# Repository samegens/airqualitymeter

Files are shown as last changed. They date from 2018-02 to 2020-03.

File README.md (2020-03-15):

# Air quality meter
Air quality meter using of-the-shelf components to measure dust particles, CO2, benzene and other nasty stuff.

# Prerequisites
- [Visual Studio Community](https://www.visualstudio.com/vs/community/)
- [Visual Micro](http://www.visualmicro.com)
- [Arduino core for ESP8266](https://github.com/esp8266/Arduino)

# Hardware
- [Wemos D1 Mini Lite](https://www.tinytronics.nl/shop/nl/arduino/wemos/wemos-d1-mini-lite-esp8285-ch340)
- [SDS-011 dust sensor](https://www.tinytronics.nl/shop/nl/sensoren/temperatuur-lucht-vochtigheid/nova-sds011-hoge-precisie-laser-stofsensor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)
- [3x TM1637 4-digit display](https://www.tinytronics.nl/shop/nl/verlichting/led-segment-display/robotdyn-segmenten-display-module-4-karakters-decimalen-wit-tm1637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)
- [MQ-135 gas sensor](https://www.tinytronics.nl/shop/nl/sensoren/temperatuur-lucht-vochtigheid/mq-135-gas-sensor-module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)
- breadboard
- wires, [male to male](https://www.tinytronics.nl/shop/nl/kabels/prototype-draden/dupont-jumper-draad-male-male-10cm-10-draden) and [male to female](https://www.tinytronics.nl/shop/nl/kabels/prototype-draden/dupont-jumper-draad-male-female-10cm-10-draden)
- enclosure, I used a cardboard box of 8cm x 21cm x 15cm
- power bank, with a USB cable that ends in a micro-USB connector
- stuff to attach the MQ-135 and displays to the enclosure. I used some electric wire (see photos).

# Schematic

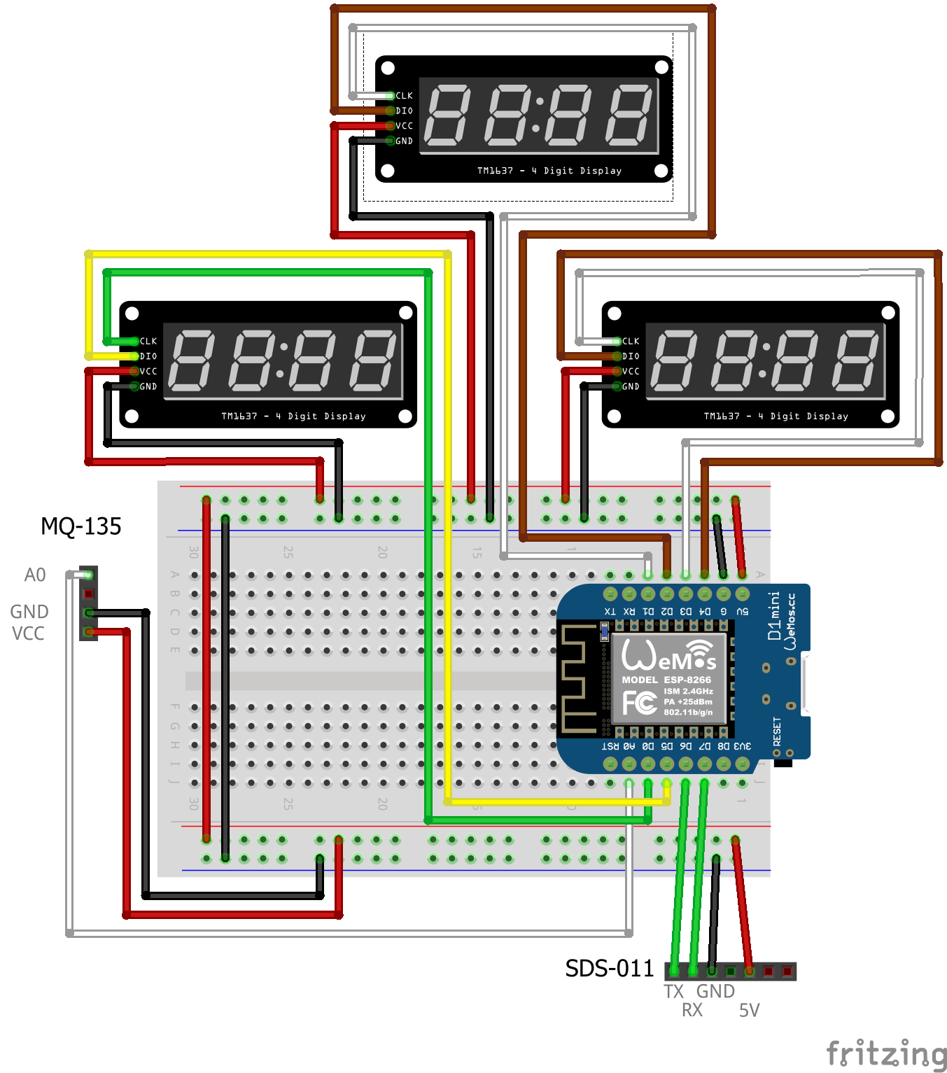
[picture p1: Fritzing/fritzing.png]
Fritzing


# Software

1. Open AirQualityMeter.sln in Visual Studio.
2. Adjust the brightness of the digits to your liking (search for `setBacklight` in AirQualityMeter.ino).
3. If you're using different pins than indicated in the schematic, change the the pin definitions in AirQualityMeter.ino.
4. Select 'Wemos D1 mini Lite' in the board drop-down.
5. Select the correct COM port.
6. Build and upload. You might need to remove the D1 from the breadboard when uploading, I sometimes got a sync error with the D1 on the breadboard and everything connected.
7. Let the meter burn in for at least 24 hours. During that time the top display will alternate between the measured gas concentration en between the current Rzero\*10.
8. When the Rzero\*10 has stabilized after burn-in, open MQ135.h in Visual Studio and on line 27 change the value of RZERO to the displayed value / 10.
9. Open AirQualityMeter.ino and comment out the MQ135_CALIBRATION define.
10. Build and upload. 
11. Each time you turn on the meter, the MQ135 needs to heat up, this may take a while (20 minutes or more).
12. You need to calibrate the MQ135, see [this article](https://www.codrey.com/electronic-circuits/how-to-use-mq-135-gas-sensor/).

# End result

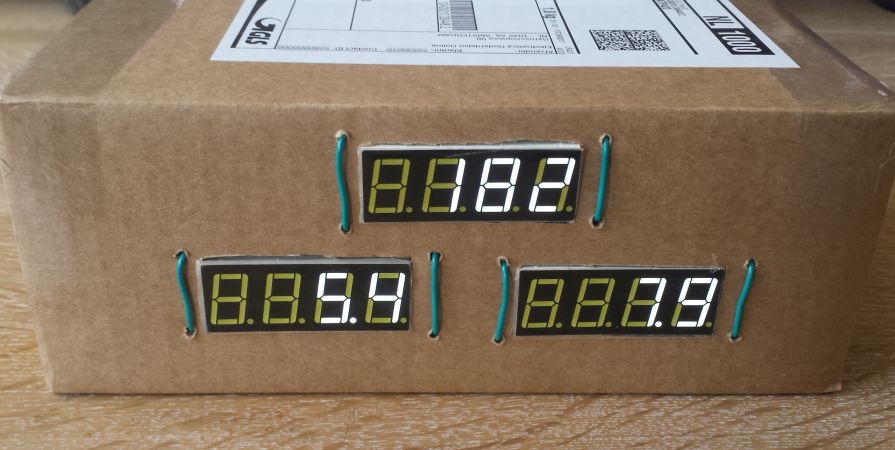
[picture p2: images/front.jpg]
front Front


The top display shows the [ppm](https://en.wikipedia.org/wiki/Parts-per_notation) of NH3, NOx, alcohol, Benzene, smoke and CO2. The left display shows µg/m³ of [PM2.5](https://en.wikipedia.org/wiki/Particulates), the right one shows µg/m³ of [PM10](https://en.wikipedia.org/wiki/Particulates).

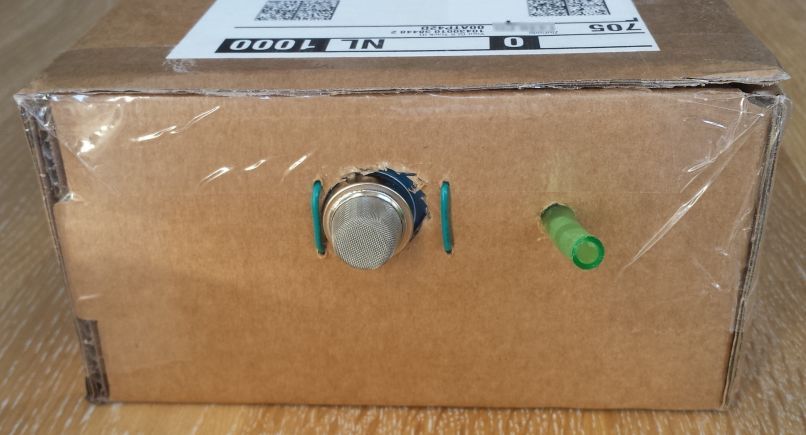
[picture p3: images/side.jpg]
side Side


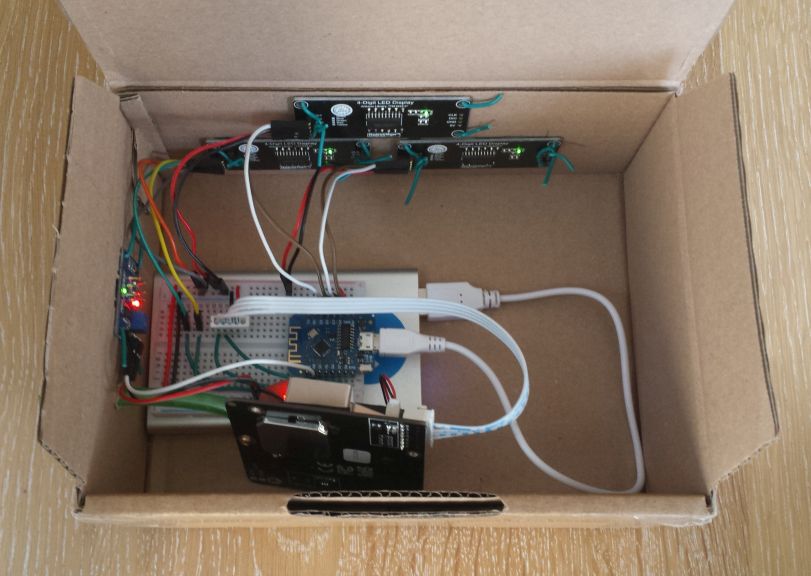
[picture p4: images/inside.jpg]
inside Inside


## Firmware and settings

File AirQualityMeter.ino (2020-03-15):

/*
 Name:		AirQualityMeter.ino
 Created:	2/18/2018 11:26:28 AM
 Author:	Sebastiaan
*/

#include "libraries\SDS011_sensor\SDS011.h"
#include "libraries\arduino-tm1637-master\src\SevenSegmentTM1637.h"
#include "libraries\MQ135-master\MQ135.h"

#define PIN_RX D6
#define PIN_TX D7
SDS011 mySDS;

#define CLK_1 D3
#define DIO_1 D4
SevenSegmentTM1637 tm1637_p25(CLK_1, DIO_1);

#define CLK_2 D0
#define DIO_2 D5
SevenSegmentTM1637 tm1637_p10(CLK_2, DIO_2);

#define CLK_3 D1
#define DIO_3 D2
SevenSegmentTM1637 tm1637_mq135(CLK_3, DIO_3);

#define PIN_MQ135 A0
MQ135 mq135_sensor = MQ135(PIN_MQ135);

// Comment this define when you found a stable Rzero.
//#define MQ135_CALIBRATION
#ifdef MQ135_CALIBRATION
int mq135Iteration = 0;
#endif

void setup()
{
	Serial.begin(115200);
	mySDS.begin(PIN_RX, PIN_TX);
	tm1637_p25.begin();
	tm1637_p25.setBacklight(40);
	tm1637_p10.begin();
	tm1637_p10.setBacklight(40);
	tm1637_mq135.begin();
	tm1637_mq135.setBacklight(40);

	tm1637_p25.printRaw(tm1637_p25.encode((char)('0')), 0);
	tm1637_p25.printRaw(tm1637_p25.encode((char)('1')), 1);
	tm1637_p25.printRaw(tm1637_p25.encode((char)('2')), 2);
	tm1637_p25.printRaw(tm1637_p25.encode((char)('3')), 3);

	tm1637_p10.printRaw(tm1637_p10.encode((char)('4')), 0);
	tm1637_p10.printRaw(tm1637_p10.encode((char)('5')), 1);
	tm1637_p10.printRaw(tm1637_p10.encode((char)('6')), 2);
	tm1637_p10.printRaw(tm1637_p10.encode((char)('7')), 3);

	tm1637_mq135.printRaw(tm1637_mq135.encode((char)('8')), 0);
	tm1637_mq135.printRaw(tm1637_mq135.encode((char)('9')), 1);
	tm1637_mq135.printRaw(tm1637_mq135.encode((char)('0')), 2);
	tm1637_mq135.printRaw(tm1637_mq135.encode((char)('1')), 3);

	delay(1000);
}


void readMq135()
{
	int nr_samples = 10;
	int delay_per_sample = 100;

	float rzero_total = 0.0;
	float ppm_total = 0.0;
	for (int i = 0; i < nr_samples; i++)
	{
		float rzero = mq135_sensor.getRZero();
		float ppm = mq135_sensor.getPPM();
		rzero_total += rzero;
		ppm_total += ppm;
		delay(delay_per_sample);
	}

	float rzero = rzero_total / nr_samples;
	float ppm = ppm_total / nr_samples;
	Serial.print("MQ135 RZero: ");
	Serial.print(rzero);
	Serial.print("\t PPM: ");
	Serial.println(ppm);

	int value_for_display = (int)ppm;
#ifdef MQ135_CALIBRATION
	// Switch between ppm and rzero (needed for calibration).
	if ((mq135Iteration / 3) % 2 == 1)
		value_for_display = (int)(rzero * 10);
	mq135Iteration++;
#endif

	if (value_for_display < 0)
		value_for_display = 0;
	if (value_for_display > 9999)
		value_for_display = 9999;

	char digits[5] = { '\0' };
	digits[0] = '0' + value_for_display / 1000;
	digits[1] = '0' + (value_for_display % 1000) / 100;
	digits[2] = '0' + (value_for_display % 100) / 10;
	digits[3] = '0' + value_for_display % 10;

	tm1637_mq135.print(digits);
}


void updateDisplay(SevenSegmentTM1637& display, float value)
{
	int intValue = (int)(value * 10);
	char ch;
	ch = '0' + intValue / 1000;
	display.printRaw(display.encode(ch), 0);

	ch = '0' + (intValue % 1000) / 100;
	display.printRaw(display.encode(ch), 1);

	ch = '0' + (intValue % 100) / 10;
	// Enable decimal dot on third digit to function as decimal separator. Highest bit turns this decimal dot on.
	display.printRaw(display.encode(ch) | B10000000, 2);

	ch = '0' + intValue % 10;
	display.printRaw(display.encode(ch), 3);
}


void readSds011()
{
	float p25;
	float p10;
	int error = mySDS.read(&p25, &p10);
	if (!error)
	{
		Serial.println("P2.5: " + String(p25));
		Serial.println("P10:  " + String(p10));
		updateDisplay(tm1637_p25, p25);
		updateDisplay(tm1637_p10, p10);

	}
	else
	{
		Serial.println("error");
		tm1637_p25.write("Err");
		tm1637_p10.write("Err");
	}
}


void loop() 
{
	readMq135();
	readSds011();

	// No delay because reading the Mq135 already has a delay
	//delay(1000);
}

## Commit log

2018-02-22 Initial commit.
    [Demo Sketch.fz, Demo Sketch.fzz, fritzing.fzz]
2018-02-22 Added: info about attaching.
2018-02-24 Changed: increased backlight intensity because the digits were barely visible in daylight.
    Changed: always showing zeroes in display, simpler and always correct.
    Added: define to enable/disable MQ135 calibration.
    [AirQualityMeter.ino]
2020-03-15 Changed: calibration value Rzero after calibration in fresh air.
    Fixed: mq135Iteration should only be used within ifdef.
    Fixed: incorrect filename at top of AirQualityMeter.ino.
    [AirQualityMeter.ino]
